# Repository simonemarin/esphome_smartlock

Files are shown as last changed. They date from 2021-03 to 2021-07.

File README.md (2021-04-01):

# esphome_smartlock

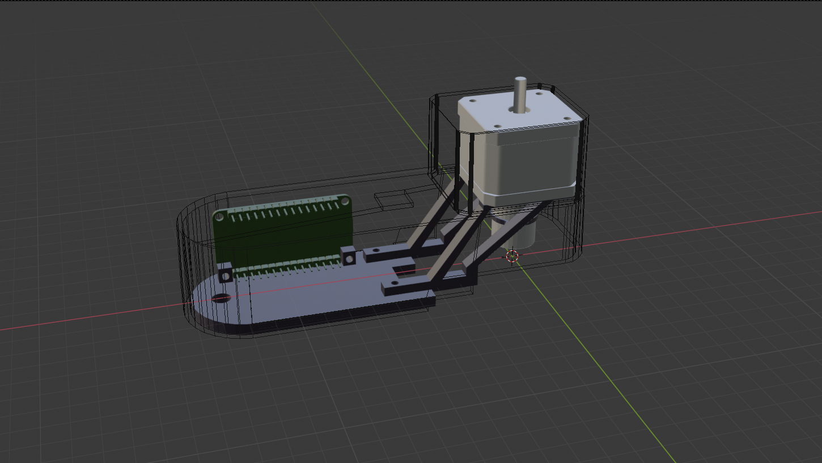
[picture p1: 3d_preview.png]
3D preview


Starter project to build a smart lock device using ESPhome https://esphome.io/, a NEMA17, a stepper driver, a figerprint sensor (optional), a couple of switches, a passive buzzer and some 3d printed parts.

## Disclaimer
This is an ad-hoc project which worked for my door but may not for yours, still it may be a starting point for your project, feel free to join and feed back.

## Components used:
- NodeMCU v2 (esp8266) https://aliexpress.ru/item/32665100123.html
- NEMA17 (dual shaft is a plus if you want to unlock yourself when the power is off) https://www.aliexpress.com/item/32906078178.html
- stepper driver a4988 https://www.aliexpress.com/item/1005001374747956.html
- 12v power supply https://www.aliexpress.com/item/1005002193618385.html
- a door lock cylinder with handle, the one I used has a D shaped 8mm shaft https://www.leroymerlin.es/fp/82337473/cilindro-niquelado-llave-puntos-boton-standers
- 8mm to 5mm shaft coupler https://es.aliexpress.com/item/4000259884542.html 
- GROW fingerprint sensor 502aw but any of the series should work http://www.zjgrow.com/GROW-Capacitive-Fingerprint-Scanner-Sensor-Module-Reader-Access-Control-c39195/
- a small switch (this is the only invasive part, you have to place the switch inside the lock system, it may opt out and do some software magic)
- a switch for the frontend (also optional)
- access to a 3D printer (I am including the blender project, you will have to adapt it to your door)

To add fingerprint functionality you have to pull a specific branch of ESPhome, thay may change soon, please follow up here https://github.com/esphome/esphome/pull/1356

To store fingerprints and do something with it add https://github.com/simonemarin/esphome_smartlock/blob/main/ha_fingerprint_package.yaml to Home Assistant 

## How to connect

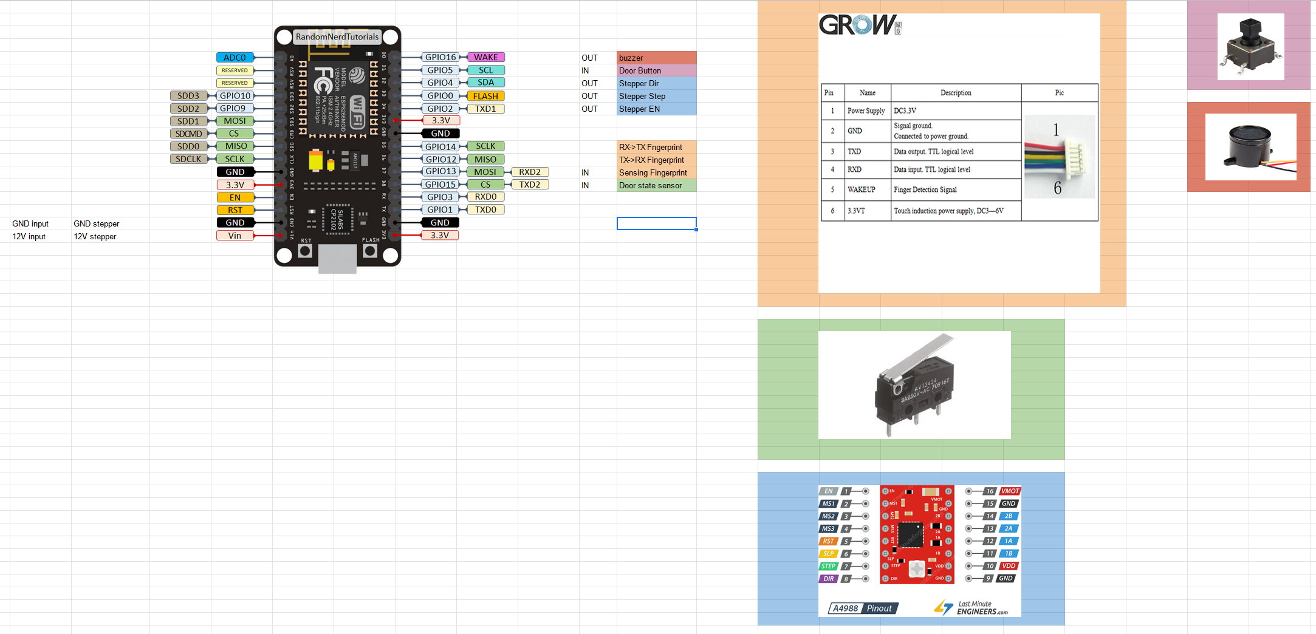
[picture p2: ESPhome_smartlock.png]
how to connect


## so what can it do for me?
- big surprise! If the power line is not down it will open or close the door for you
- there are 3 main actions: open the latch (same as opening with the handle), full open (unlocks and opens the latch), close the door (same as closing with keys)
- these 3 main actions can be triggered by either of the following inputs: you press the button on the lock itself, you swipe your finger on the sensor, you press a button on Home Assistant, you log in ESPhome web interface and press a button

## reliability
- the software reliability is excellent, also thanks to ESPhome scripting you are not bound to have Home Assistant up and running
- the direct drive system also is very reliable but, being mine and old door with old mecanics, from time to time the stepper seems not to be able to unlock the latch, normally it works at the second try. The plan is to use a TMC 2130 driver with StallGuard so we can force the motor to run until the latch is open, then back it down to home position
- and yes I am using it daily, I am also using ESPhome for the street door so basically I am not using keys anymore

## future plans
- as mentioned upgrading to TCM2130 drivers
- not directly related but a morse code reader for the street door bell so I can open it if I forget the phone or have no battery
- a better case design, something not so boxy

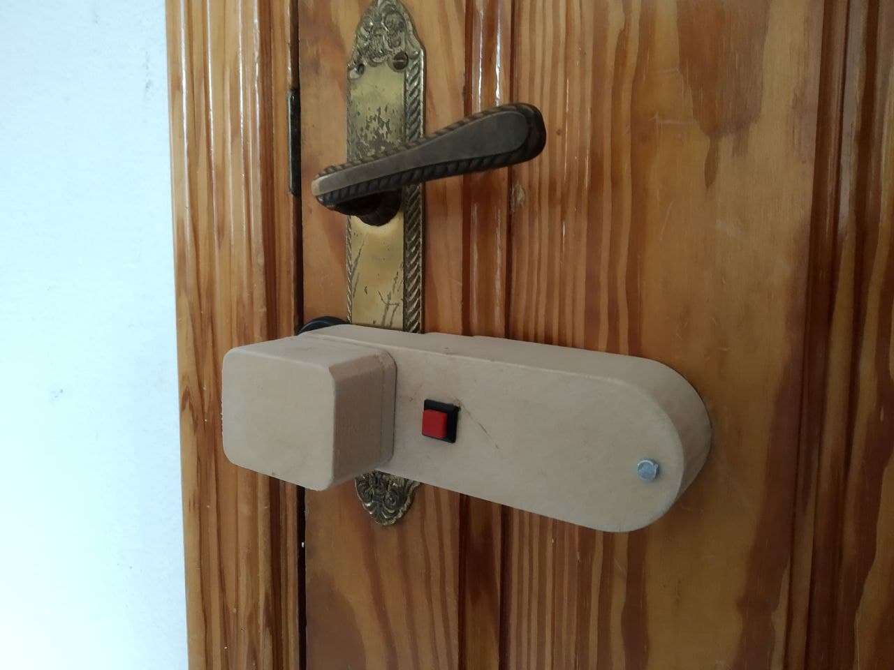
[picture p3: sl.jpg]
3preview


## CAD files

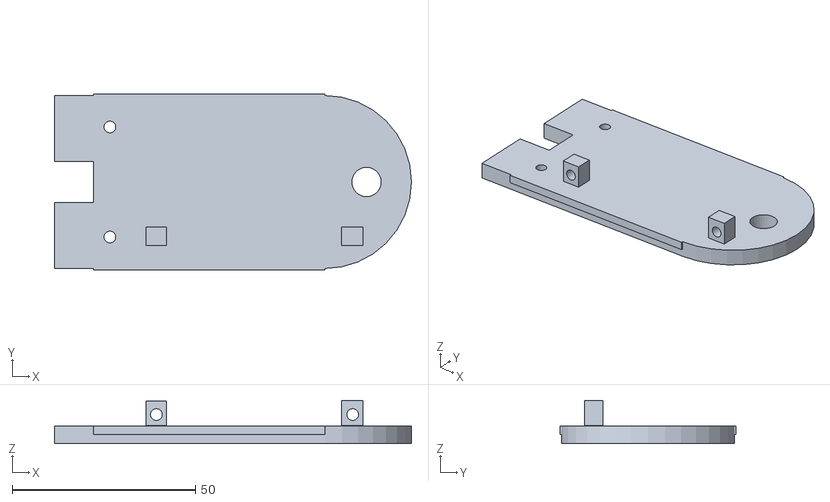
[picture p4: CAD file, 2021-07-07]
base.stl
97.4 x 48.1 x 11.8

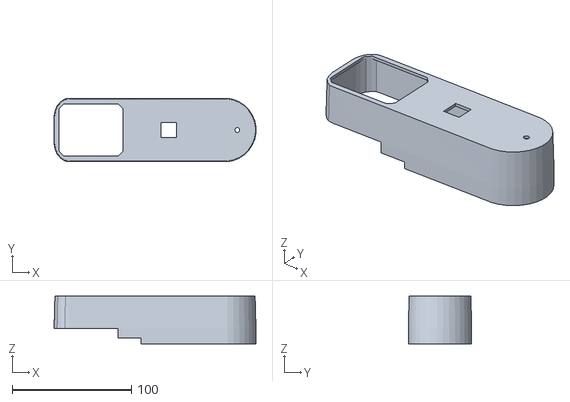
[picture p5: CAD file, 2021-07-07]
case.stl
169.5 x 53.3 x 40.3

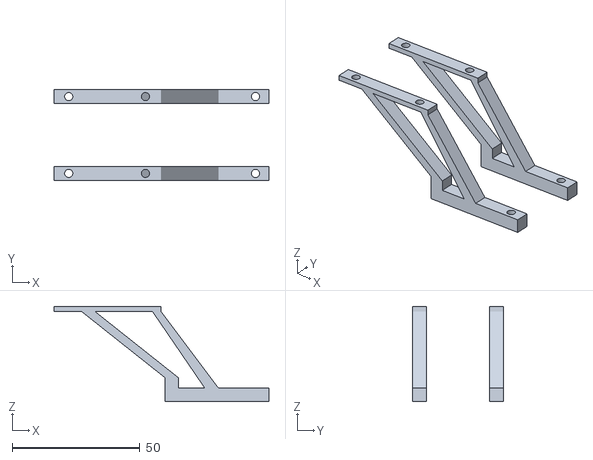
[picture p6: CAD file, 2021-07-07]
anchor.stl
84.0 x 35.7 x 37.3

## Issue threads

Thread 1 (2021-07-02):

3D printing file

hamadfayyad, 2021-07-02:
Could you please provide me with a 3D printing file

Thanks!

simonemarin, 2021-07-02:
Yes I can provide .stl files but do remember that you can easily export them from Blender, which is free and that they will probably not fit your door.

simonemarin, 2021-07-07:
There you go

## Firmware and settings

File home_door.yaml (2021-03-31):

esphome:
  name: home_door
  platform: ESP8266
  board: nodemcuv2

wifi:
  ssid: !secret wifi_ssid
  password: !secret wifi_pswd

  ap:
    ssid: "Home Door Fallback Hotspot"
    password: !secret wifi_pswd

captive_portal:

web_server:
  port: 80

# Enable logging
logger:
  level: INFO

ota:

globals:
  - id: steps_full
    type: int
    initial_value: '3200'
  - id: steps_open_latch
    type: int
    initial_value: '-1288'
  - id: steps_offset_latch
    type: int
    initial_value: '-200'
  - id: beeps
    type: int

uart:
  rx_pin: D5
  tx_pin: D6
  baud_rate: 57600

fingerprint_grow:
  sensing_pin: D7
  on_finger_scan_matched:
    - homeassistant.event:
        event: esphome.test_fingerprint_grow_finger_scan_matched
        data:
          finger_id: !lambda 'return finger_id;'
          confidence: !lambda 'return confidence;'
    - fingerprint_grow.aura_led_control:
        state: BREATHING
        speed: 200
        color: BLUE
        count: 1
    - switch.turn_on: open_home_door
  on_finger_scan_unmatched:
    - homeassistant.event:
        event: esphome.test_fingerprint_grow_finger_scan_unmatched
    - fingerprint_grow.aura_led_control:
        state: FLASHING
        speed: 25
        color: RED
        count: 2
  on_enrollment_scan:
    - homeassistant.event:
        event: esphome.test_fingerprint_grow_enrollment_scan
        data:
          finger_id: !lambda 'return finger_id;'
          scan_num: !lambda 'return scan_num;'
    - fingerprint_grow.aura_led_control:
        state: FLASHING
        speed: 25
        color: BLUE
        count: 2
  on_enrollment_done:
    - homeassistant.event:
        event: esphome.test_fingerprint_grow_node_enrollment_done
        data:
          finger_id: !lambda 'return finger_id;'
    - fingerprint_grow.aura_led_control:
        state: BREATHING
        speed: 100
        color: BLUE
        count: 2
  on_enrollment_failed:
    - homeassistant.event:
        event: esphome.test_fingerprint_grow_enrollment_failed
        data:
          finger_id: !lambda 'return finger_id;'
    - fingerprint_grow.aura_led_control:
        state: FLASHING
        speed: 25
        color: RED
        count: 4

switch:
  - platform: template
    name: "Open home door"
    id: open_home_door
    turn_on_action:
      - stepper.report_position:
          id: nema
          position: 0
      - output.turn_on: stepper_en
      - if:
          condition:
            binary_sensor.is_on: door_state
          then:
            - stepper.set_target:
                id: nema
                target: !lambda |-
                  return id(steps_full)*-1 + id(steps_open_latch);
            - wait_until:
                lambda: return id(nema).current_position == id(steps_full)*-1 + id(steps_open_latch);
            - delay: 2s
            - stepper.set_target:
                id: nema
                target: -3200
            - wait_until:
                lambda: return id(nema).current_position == -3200;
          else:          
            - stepper.set_target:
                id: nema
                target: -1288
            - wait_until:
                lambda: return id(nema).current_position == -1288;
            - delay: 2s
            - stepper.set_target:
                id: nema
                target: -100
            - wait_until:
                lambda: return id(nema).current_position == -200; 
      - output.turn_off: stepper_en
      - switch.turn_off: open_home_door
  - platform: template
    name: "Close home door"
    id: close_home_door
    turn_on_action:
      - if:
          condition:
            binary_sensor.is_off: door_state
          then:         
            - script.execute: close_door

output:
  - platform: esp8266_pwm
    pin: D0
    frequency: 1000 Hz
    id: buzzer
  - platform: gpio
    pin: D4
    inverted: True
    id: stepper_en

rtttl:
  output: buzzer

stepper:
  - platform: a4988
    id: nema
    step_pin: D3
    dir_pin: D2
    max_speed: 3000 steps/s
    acceleration: 5000
    deceleration: 5000

sensor:
  - platform: fingerprint_grow
    fingerprint_count:
      name: "Fingerprint Count"
    status:
      name: "Fingerprint Status"
    capacity:
      name: "Fingerprint Capacity"
    security_level:
      name: "Fingerprint Security Level"
    last_finger_id:
      name: "Fingerprint Last Finger ID"
    last_confidence:
      name: "Fingerprint Last Confidence"
      
binary_sensor:
  - platform: fingerprint_grow
    name: "Fingerprint Enrolling"
  - platform: gpio
    pin: D1
    name: "Door Button"
    on_click:
      min_length: 100ms
      then:
        - rtttl.play: "one short:d=4,o=5,b=100:16e6"
        - delay: 5s
        - script.execute: close_door
        - wait_until:
            not:
              script.is_running: close_door
        - rtttl.play: "two short:d=4,o=5,b=100:16e6,16e6"

  - platform: gpio
    pin: D8
    name: "Door State ON is closed"
    device_class: door
    id: door_state
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
